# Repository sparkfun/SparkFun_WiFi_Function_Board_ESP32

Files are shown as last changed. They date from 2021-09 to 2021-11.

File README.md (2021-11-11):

SparkFun WiFi Function Board - ESP32
========================================

SparkFun WiFi Function Board - ESP32 (https://www.sparkfun.com/products/18430)

[*SparkFun WiFi Function Board - ESP32 (WRL-18430)*](https://www.sparkfun.com/products/18430)

The SparkFun MicroMod ESP32 Function Board adds additional wireless options to MicroMod Processor Boards that do not have that capability. This special function board acts as a coprocessor that takes advantage of Espressif's ESP32 WROOM to add WiFi and Bluetooth&reg; to your applications. 

At the core of the ESP32 WROOM module is the ESP32-D0WD-V3 chip which is designed to be both scalable and adaptive. ESP32 WROOM module on this board  features 16MB of flash memory, 520kB of internal SRAM, an integrated 802.11 b/g/n WiFi transceiver, and dual-mode Bluetooth capabilities. Utilizing our handy M.2 MicroMod connector, no soldering is required to connect it to your system. Simply match up the key on your processor and function board's beveled edge connector to their respective key on the M.2 connector, then secure them to the main board with screws. The ESP32 WROOM module can then be controlled using AT commands via the serial UART port.

The ESP32 Function Board comes pre-flashed with AT-command firmware and acts as a serial-to-WiFi gateway. Next to the module is a USB-C connector and CP2102 USB-to-serial converter. Whether you want to add AT commands of your own, or flash custom firmware on the ESP32, you can use this port to reprogram the ESP32.

Repository Contents
-------------------

* **/Hardware** - Eagle design files (.brd, .sch)
* **/Production** - Production panel files (.brd)

Documentation
--------------

* **[Hookup Guide](https://learn.sparkfun.com/tutorials/1998)** - Basic hookup guide

Product Versions
----------------

* [WRL-18430](https://www.sparkfun.com/products/18430) - Initial release

Version History
---------------

* v1.0 - Initial Release

License Information
-------------------

This product is _**open source**_! 

Please review the LICENSE.md file for license information. 

If you have any questions or concerns on licensing, please contact technical support on our [SparkFun forums](https://forum.sparkfun.com/viewforum.php?f=152).

Distributed as-is; no warranty is given.

- Your friends at SparkFun.

_<COLLABORATION CREDIT>_

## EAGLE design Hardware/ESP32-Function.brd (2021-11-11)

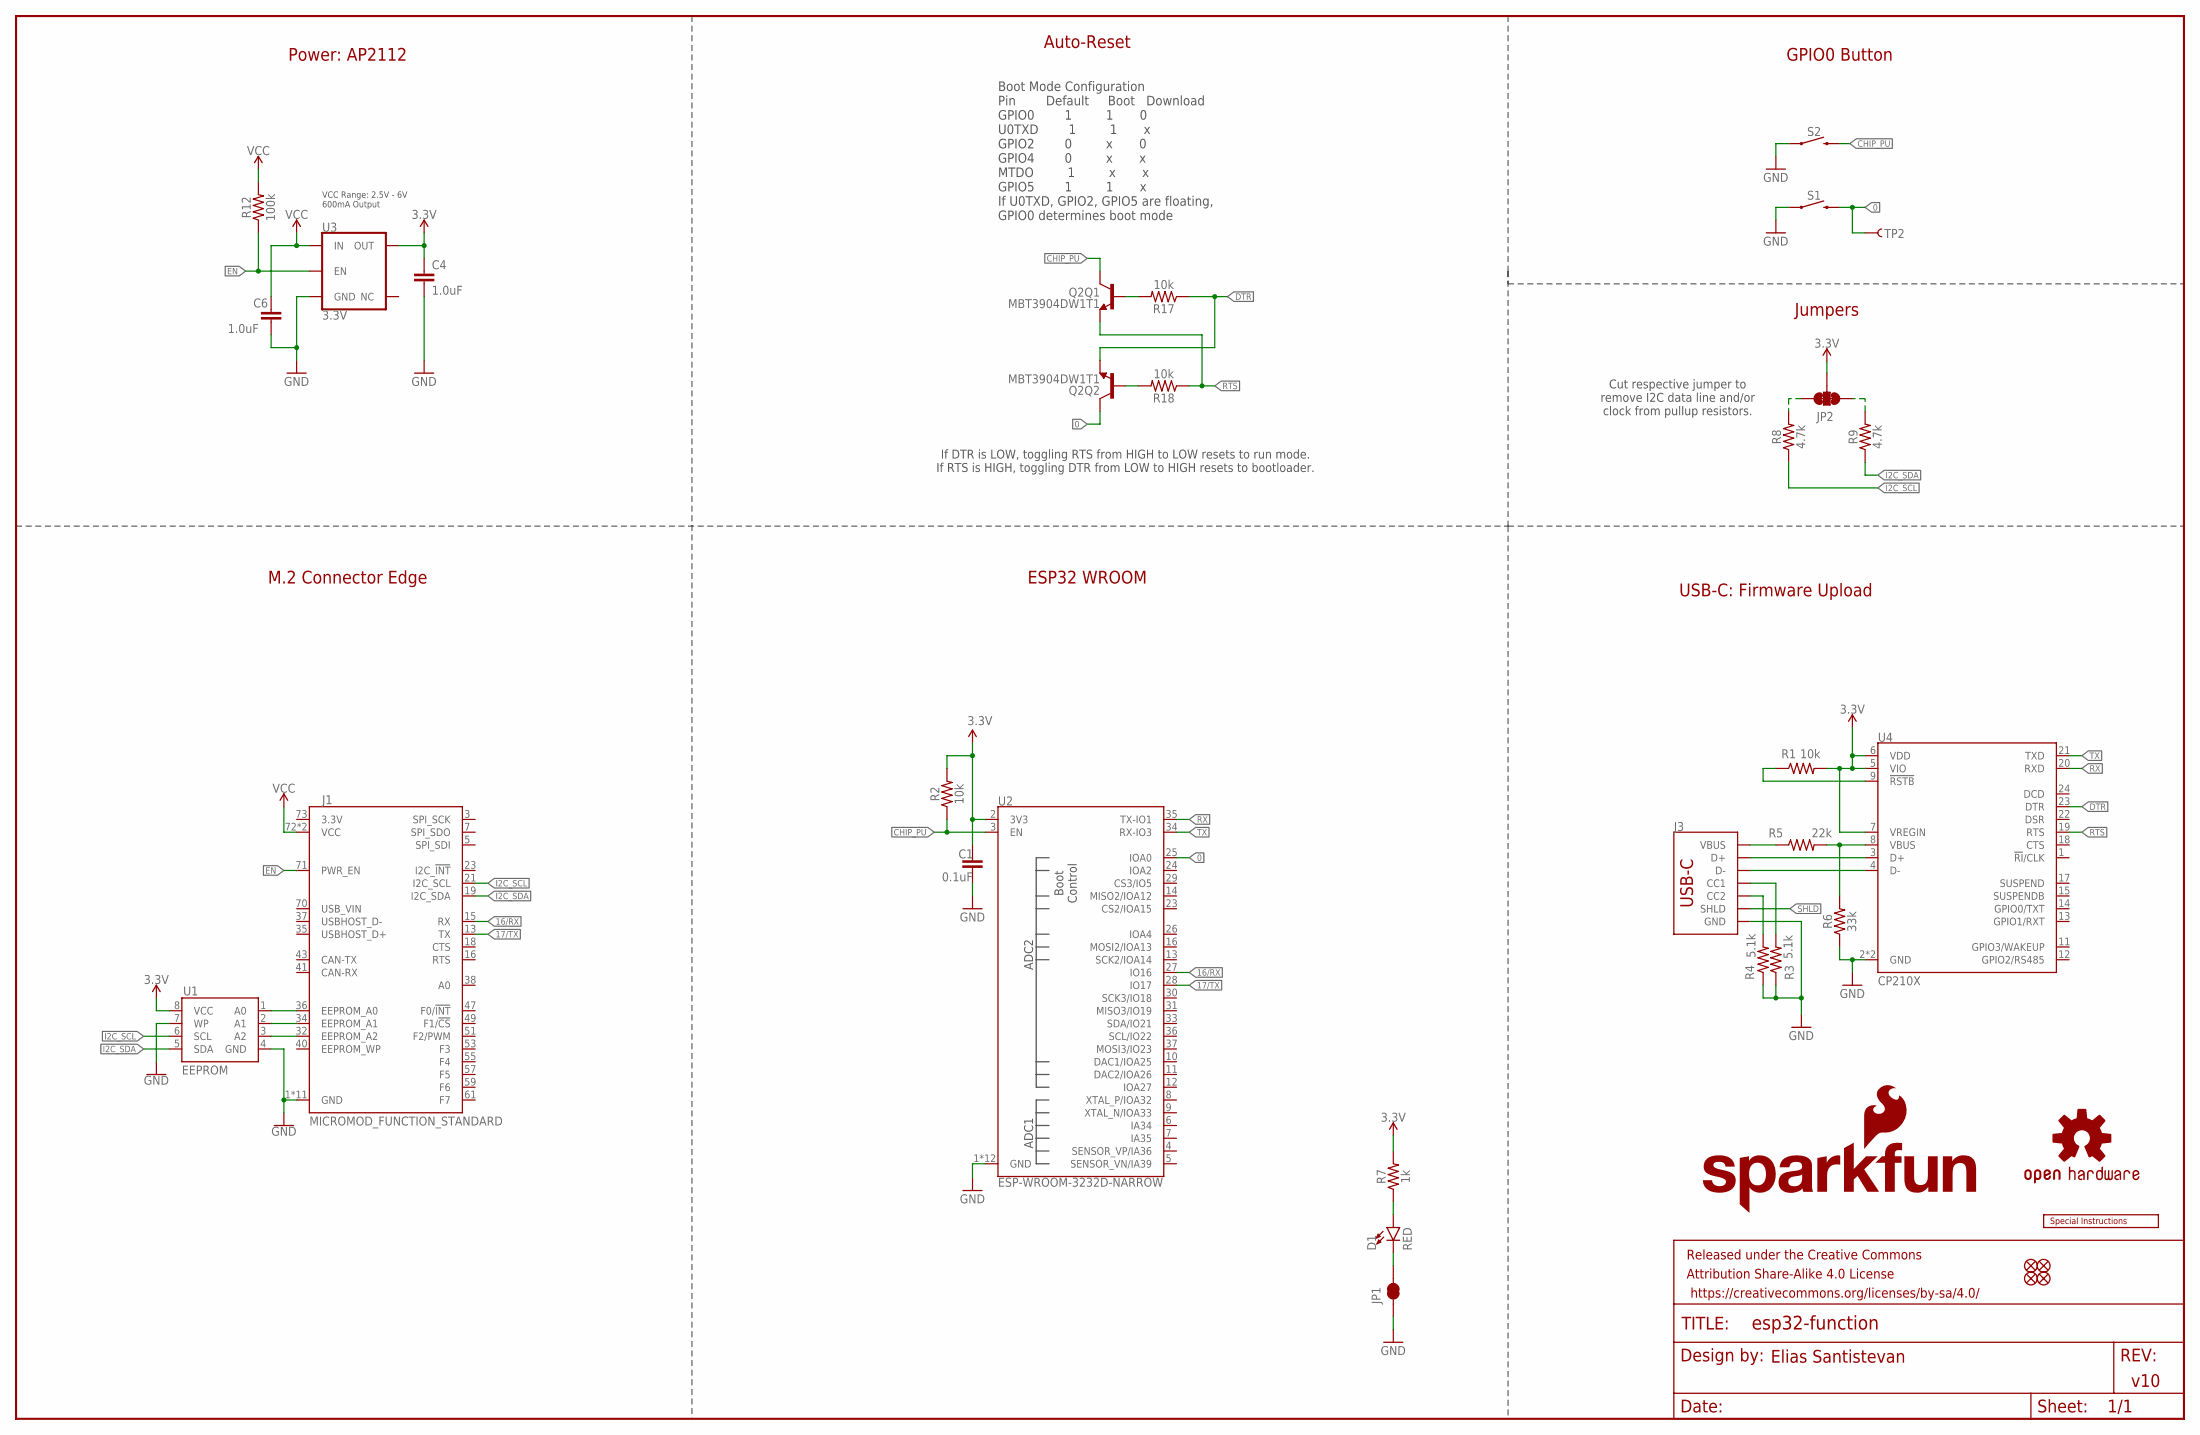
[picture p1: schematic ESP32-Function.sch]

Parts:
C1: 0.1uF; 0603
C4, C6: 1.0uF; 0603
D1: RED; LED-0603
FD1, FD2, FD3, FD4: FIDUCIAL1X2; FIDUCIAL-1X2
FRAME2: FRAME-LEDGER; CREATIVE_COMMONS
J1: MICROMOD_FUNCTION_STANDARD; M.2-CARD-E-22_FUNCTION_STANDARD
J3: USB_C_2-LAYER_PADS; USB-C-16P-2LAYER-PADS
JP1: JUMPER-SMT_2_NC_TRACE_SILK; SMT-JUMPER_2_NC_TRACE_SILK
JP2: JUMPER-SMT_3_2-NC_TRACE_SILK; SMT-JUMPER_3_2-NC_TRACE_SILK
LOGO1: SPECIAL_INSTRUCTIONS-ORDERING; ORDERING_INSTRUCTIONS
LOGO2: SFE_LOGO_NAME_FLAME.2_INCH; SFE_LOGO_NAME_FLAME_.2
LOGO3: OSHW-LOGOS; OSHW-LOGO-S
Q2: MBT3904DW1T1; SC70-6
R1, R2, R17, R18: 10k; 0603
R3, R4: 5.1k; 0603
R5: 22k; 0603
R6: 33k; 0603
R7: 1k; 0603
R8, R9: 4.7k; 0603
R12: 100k; 0603
S1, S2: MOMENTARY-SWITCH-SPST-SMD-5.2MM-TALL; TACTILE_SWITCH_SMD_5.2MM
TP2: TEST-POINTTP_15TH_THRU; TP_15TH
U1: EEPROM; SO08
U2: ESP-WROOM-3232D-NARROW; ESP-WROOM-32D-NARROW
U3: 3.3V; SOT23-5
U4: CP210X; QFN24

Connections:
0: Q2.6 (C), S1.3 (2), TP2.1, U2.25 (IOA0)
3.3V: C1.1, C4.1, JP2.2, R1.2, R2.2, R7.2, U1.8 (VCC), U2.2 (3V3), U3.5 (OUT), U4.5 (VIO), U4.6 (VDD), U4.7 (VREGIN)
16/RX: J1.15 (RX), U2.27 (IO16)
17/TX: J1.13 (TX), U2.28 (IO17)
CHIP_PU: Q2.3 (C), R2.1, S2.3 (2), U2.3 (EN)
D+: J3.A6 (D+), J3.B6 (D+), U4.3 (D+)
D-: J3.A7 (D-), J3.B7 (D-), U4.4 (D-)
DTR: Q2.1 (E), R17.1, U4.23 (DTR)
EN: J1.71 (PWR_EN), R12.1, U3.3 (EN)
GND: C1.2, C4.2, C6.2, J1.1 (GND), J1.33 (GND), J1.39 (GND), J1.45 (GND), J1.75 (GND), J1.GND1 (GND), J1.GND2 (GND), J1.GND3 (GND), J1.GND4 (GND), J1.GND5 (GND), J1.GND6 (GND), J3.GND, J3.GND2 (GND), JP1.1, R3.1, R4.1, R6.1, S1.1, S2.1, U1.4 (GND), U1.7 (WP), U2.1 (GND), U2.15 (GND), U2.38 (GND), U2.GND1 (GND), U2.GNDT1 (GND), U2.GNDT2 (GND), U2.GNDT3 (GND), U2.GNDT4 (GND), U2.GNDT5 (GND), U2.GNDT6 (GND), U2.GNDT7 (GND), U2.GNDT8 (GND), U3.2 (GND), U4.2 (GND), U4.PAD (GND)
I2C_SCL: J1.21 (I2C_SCL), R8.1, U1.6 (SCL)
I2C_SDA: J1.19 (I2C_SDA), R9.1, U1.5 (SDA)
unnamed: R1.1, U4.9 (!RSTB)
unnamed: J3.A5 (CC1), R3.2
unnamed: J3.VBUS1 (VBUS), J3.VBUS2 (VBUS), R5.1
unnamed: R5.2, R6.2, U4.8 (VBUS)
unnamed: J3.B5 (CC2), R4.2
unnamed: D1.C, JP1.2
unnamed: D1.A, R7.1
unnamed: J1.32 (EEPROM_A2), U1.3 (A2)
unnamed: J1.34 (EEPROM_A1), U1.2 (A1)
unnamed: Q2.5 (B), R17.2
unnamed: J1.36 (EEPROM_A0), U1.1 (A0)
unnamed: Q2.2 (B), R18.2
unnamed: JP2.1, R9.2
unnamed: JP2.3, R8.2
RTS: Q2.4 (E), R18.1, U4.19 (RTS)
RX: U2.35 (TX-IO1), U4.20 (RXD)
SHLD: J3.SHLD1 (SHLD), J3.SHLD2 (SHLD), J3.SHLD3 (SHLD), J3.SHLD4 (SHLD)
TX: U2.34 (RX-IO3), U4.21 (TXD)
VCC: C6.1, J1.72 (VCC), J1.74 (VCC), R12.2, U3.1 (IN)

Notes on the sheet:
Elias Santistevan
v10
Boot Mode Configuration Pin Default Boot Download GPIO0 1 1 0 U0TXD 1 1 x GPIO2 0 x 0 GPIO4 0 x x MTDO 1 x x GPIO5 1 1 x If U0TXD, GPIO2, GPIO5 are floating, GPIO0 determines boot mode
Auto-Reset
If DTR is LOW, toggling RTS from HIGH to LOW resets to run mode. If RTS is HIGH, toggling DTR from LOW to HIGH resets to bootloader.
VCC Range: 2.5V - 6V 600mA Output
Power: AP2112
ESP32 WROOM
M.2 Connector Edge
GPIO0 Button
USB-C: Firmware Upload
Jumpers
Cut respective jumper to remove I2C data line and/or clock from pullup resistors.

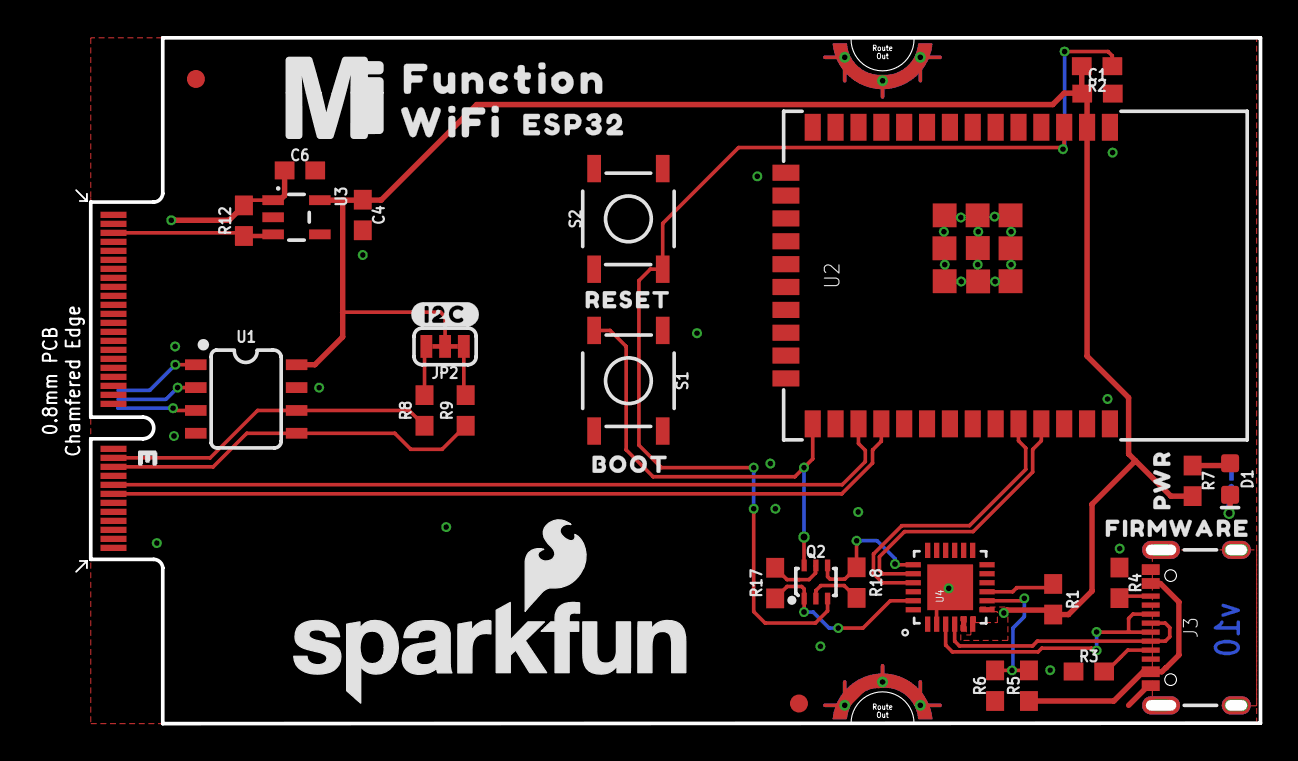
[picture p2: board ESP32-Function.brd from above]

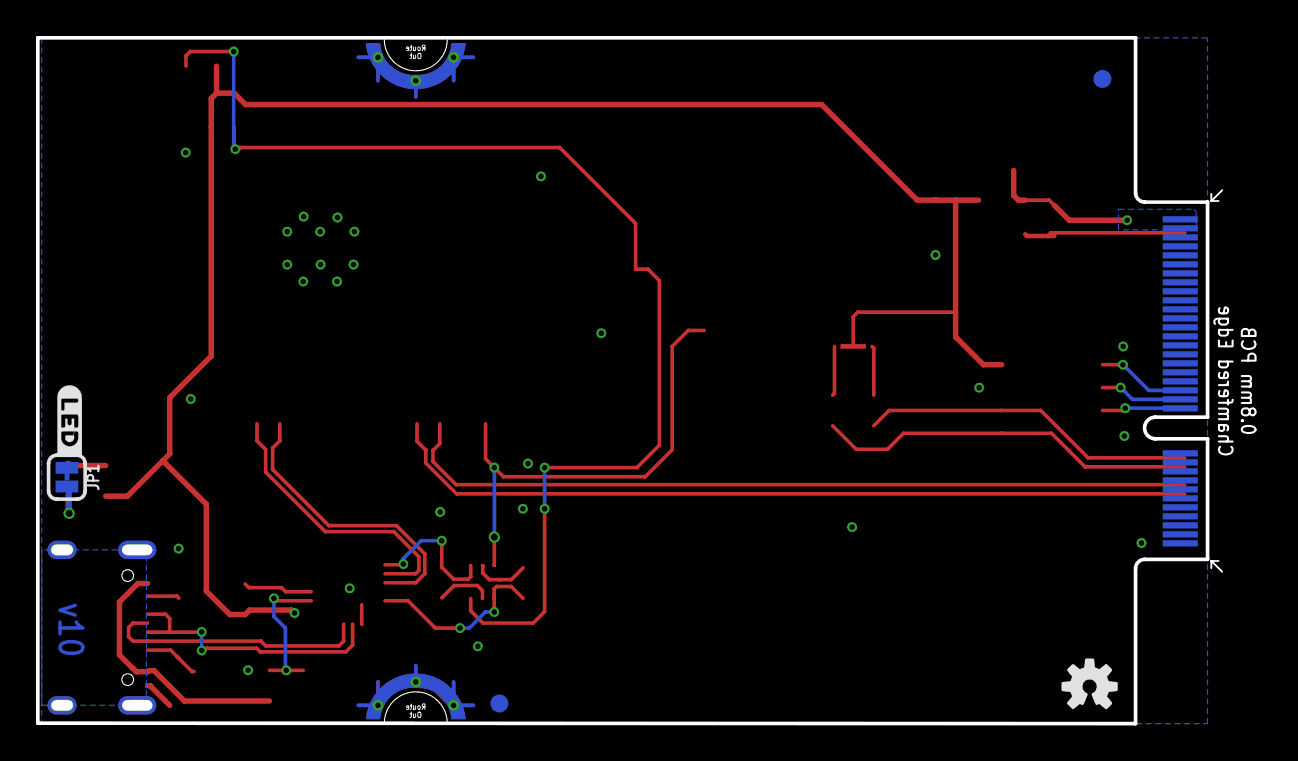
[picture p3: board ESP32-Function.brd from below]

Board: 2 copper layers, 65.8 x 38.1 mm, 46 parts (5 on the bottom side), 31 nets.

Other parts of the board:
U$1: BOOT3221
U$2: FUNCTION521
U$3: #I2C#1321540313558
U$4: ESP3212
U$5: RESET3220
U$6: MICROMOD_MI_LOGO_1
U$7: FIRMWARE3223
U$8: #LED#8
U$9: PWR3215
U$10: WIFI525

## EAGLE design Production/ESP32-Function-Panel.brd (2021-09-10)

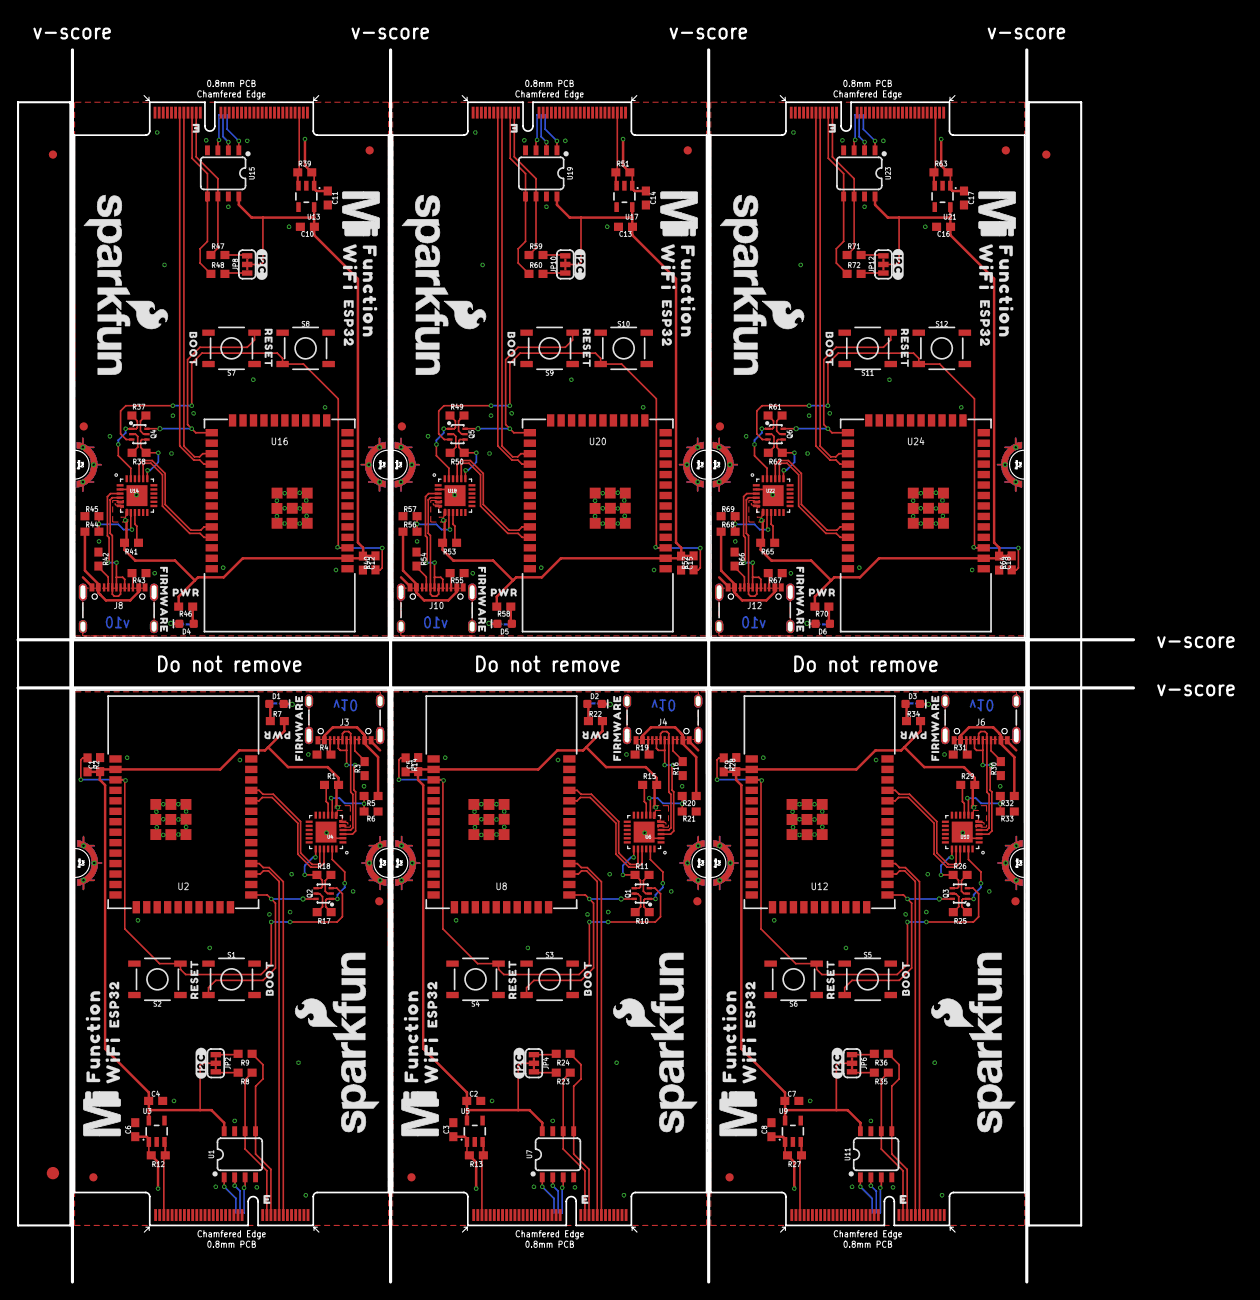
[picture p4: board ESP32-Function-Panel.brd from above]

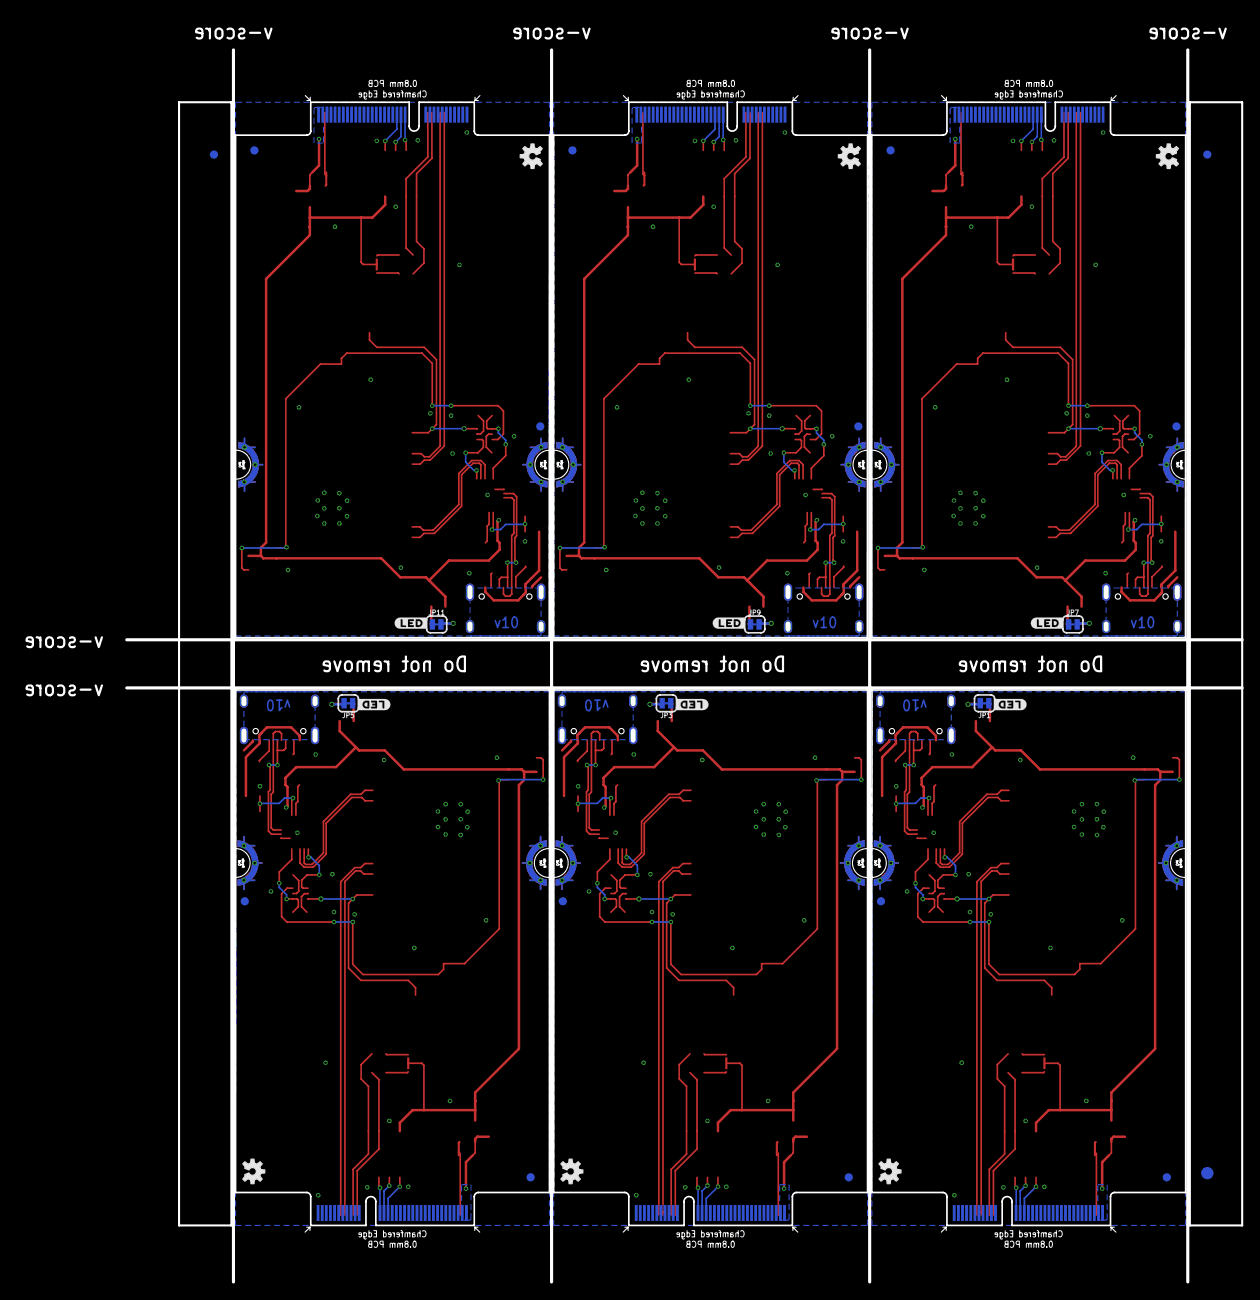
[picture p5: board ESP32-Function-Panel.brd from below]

Board: 2 copper layers, 135.4 x 149.5 mm, 270 parts (33 on the bottom side), 186 nets.

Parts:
C1, C5, C9, C12, C15, C18: 0.1uF; 0603
C2, C3, C4, C6, C7, C8, C10, C11, C13, C14, C16, C17: 1.0uF; 0603
D1, D2, D3, D4, D5, D6: RED; LED-0603
E$1, E$2, E$3, E$4: FIDUCIAL-1X2
E$5, E$6: FIDUCIAL-1.5X3
FD1, FD2, FD3, FD4, FD5, FD6, FD7, FD8, FD9, FD10, FD11, FD12, FD13, FD14, FD15, FD16, FD17, FD18, FD19, FD20, FD21, FD22, FD23, FD24: FIDUCIAL1X2; FIDUCIAL-1X2
J1, J2, J5, J7, J9, J11: MICROMOD_STANDARD; M.2-CARD-E-22_FUNCTION_STANDARD
J3, J4, J6, J8, J10, J12: USB-C-16P-2LAYER-PADS
JP1, JP3, JP5, JP7, JP9, JP11: JUMPER-SMT_2_NC_TRACE_SILK; SMT-JUMPER_2_NC_TRACE_SILK
JP2, JP4, JP6, JP8, JP10, JP12: JUMPER-SMT_3_2-NC_TRACE_SILK; SMT-JUMPER_3_2-NC_TRACE_SILK
LOGO1, LOGO2, LOGO5, LOGO7, LOGO9, LOGO11: SFE_LOGO_NAME_FLAME.2_INCH; SFE_LOGO_NAME_FLAME_.2
LOGO3, LOGO4, LOGO6, LOGO8, LOGO10, LOGO12: OSHW-LOGOS; OSHW-LOGO-S
Q1, Q2, Q3, Q4, Q5, Q6: MBT3904DW1T1; SC70-6
R1, R2, R10, R11, R14, R15, R17, R18, R25, R26, R28, R29, R37, R38, R40, R41, R49, R50, R52, R53, R61, R62, R64, R65: 10k; 0603
R3, R4, R16, R19, R30, R31, R42, R43, R54, R55, R66, R67: 5.1k; 0603
R5, R20, R32, R44, R56, R68: 22k; 0603
R6, R21, R33, R45, R57, R69: 33k; 0603
R7, R22, R34, R46, R58, R70: 1k; 0603
R8, R9, R23, R24, R35, R36, R47, R48, R59, R60, R71, R72: 4.7k; 0603
R12, R13, R27, R39, R51, R63: 100k; 0603
S1, S2, S3, S4, S5, S6, S7, S8, S9, S10, S11, S12: MOMENTARY-SWITCH-SPST-SMD-5.2MM-TALL; TACTILE_SWITCH_SMD_5.2MM
TP1, TP2, TP3, TP4, TP5, TP6: TEST-POINTTP_15TH_THRU; TP_15TH
U1, U7, U11, U15, U19, U23: EEPROM; SO08
U2, U8, U12, U16, U20, U24: ESP-WROOM-3232D-NARROW; ESP-WROOM-32D-NARROW
U3, U5, U9, U13, U17, U21: 3.3V; SOT23-5
U4, U6, U10, U14, U18, U22: CP210X; QFN24
U$1, U$11, U$21, U$31, U$41, U$51: BOOT3221
U$2, U$17, U$27, U$37, U$47, U$57: FUNCTION521
U$3, U$20, U$30, U$40, U$50, U$60: #I2C#1321540313558
U$4, U$12, U$22, U$32, U$42, U$52: ESP3212
U$5, U$14, U$24, U$34, U$44, U$54: RESET3220
U$6, U$18, U$28, U$38, U$48, U$58: MICROMOD_MI_LOGO_1
U$7, U$13, U$23, U$33, U$43, U$53: FIRMWARE3223
U$8, U$15, U$25, U$35, U$45, U$55: #LED#8
U$9, U$16, U$26, U$36, U$46, U$56: PWR3215
U$10, U$19, U$29, U$39, U$49, U$59: WIFI525

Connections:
0: Q2.6, S1.3, TP2.1, U2.25
1: Q1.6, S3.3, TP1.1, U8.25
2: Q3.6, S5.3, TP3.1, U12.25
3: Q4.6, S7.3, TP4.1, U16.25
3.3V: C1.1, C4.1, JP2.2, R1.2, R2.2, R7.2, U1.8, U2.2, U3.5, U4.5, U4.6, U4.7
3.3V1: C2.1, C5.1, JP4.2, R14.2, R15.2, R22.2, U5.5, U6.5, U6.6, U6.7, U7.8, U8.2
3.3V2: C7.1, C9.1, JP6.2, R28.2, R29.2, R34.2, U9.5, U10.5, U10.6, U10.7, U11.8, U12.2
3.3V3: C10.1, C12.1, JP8.2, R40.2, R41.2, R46.2, U13.5, U14.5, U14.6, U14.7, U15.8, U16.2
3.3V4: C13.1, C15.1, JP10.2, R52.2, R53.2, R58.2, U17.5, U18.5, U18.6, U18.7, U19.8, U20.2
3.3V5: C16.1, C18.1, JP12.2, R64.2, R65.2, R70.2, U21.5, U22.5, U22.6, U22.7, U23.8, U24.2
4: Q5.6, S9.3, TP5.1, U20.25
5: Q6.6, S11.3, TP6.1, U24.25
16/RX: J1.15, U2.27
16/RX1: J2.15, U8.27
16/RX2: J5.15, U12.27
16/RX3: J7.15, U16.27
16/RX4: J9.15, U20.27
16/RX5: J11.15, U24.27
17/TX: J1.13, U2.28
17/TX1: J2.13, U8.28
17/TX2: J5.13, U12.28
17/TX3: J7.13, U16.28
17/TX4: J9.13, U20.28
17/TX5: J11.13, U24.28
CHIP_PU: Q2.3, R2.1, S2.3, U2.3
CHIP_PU1: Q1.3, R14.1, S4.3, U8.3
CHIP_PU2: Q3.3, R28.1, S6.3, U12.3
CHIP_PU3: Q4.3, R40.1, S8.3, U16.3
CHIP_PU4: Q5.3, R52.1, S10.3, U20.3
CHIP_PU5: Q6.3, R64.1, S12.3, U24.3
D+: J3.A6, J3.B6, U4.3
D+1: J4.A6, J4.B6, U6.3
D+2: J6.A6, J6.B6, U10.3
D+3: J8.A6, J8.B6, U14.3
D+4: J10.A6, J10.B6, U18.3
D+5: J12.A6, J12.B6, U22.3
D-: J3.A7, J3.B7, U4.4
D-1: J4.A7, J4.B7, U6.4
D-2: J6.A7, J6.B7, U10.4
D-3: J8.A7, J8.B7, U14.4
D-4: J10.A7, J10.B7, U18.4
D-5: J12.A7, J12.B7, U22.4
DTR: Q2.1, R17.1, U4.23
DTR1: Q1.1, R10.1, U6.23
DTR2: Q3.1, R25.1, U10.23
DTR3: Q4.1, R37.1, U14.23
DTR4: Q5.1, R49.1, U18.23
DTR5: Q6.1, R61.1, U22.23
EN: J1.71, R12.1, U3.3
EN1: J2.71, R13.1, U5.3
EN2: J5.71, R27.1, U9.3
EN3: J7.71, R39.1, U13.3
EN4: J9.71, R51.1, U17.3
EN5: J11.71, R63.1, U21.3
GND: C1.2, C4.2, C6.2, J1.1, J1.33, J1.39, J1.45, J1.75, J1.GND1, J1.GND2, J1.GND3, J1.GND4, J1.GND5, J1.GND6, J3.GND, J3.GND2, JP1.1, R3.1, R4.1, R6.1, S1.1, S2.1, U1.4, U1.7, U2.1, U2.15, U2.38, U2.GND1, U2.GNDT1, U2.GNDT2, U2.GNDT3, U2.GNDT4, U2.GNDT5, U2.GNDT6, U2.GNDT7, U2.GNDT8, U3.2, U4.2, U4.PAD
GND1: C2.2, C3.2, C5.2, J2.1, J2.33, J2.39, J2.45, J2.75, J2.GND1, J2.GND2, J2.GND3, J2.GND4, J2.GND5, J2.GND6, J4.GND, J4.GND2, JP3.1, R16.1, R19.1, R21.1, S3.1, S4.1, U5.2, U6.2, U6.PAD, U7.4, U7.7, U8.1, U8.15, U8.38, U8.GND1, U8.GNDT1, U8.GNDT2, U8.GNDT3, U8.GNDT4, U8.GNDT5, U8.GNDT6, U8.GNDT7, U8.GNDT8
GND2: C7.2, C8.2, C9.2, J5.1, J5.33, J5.39, J5.45, J5.75, J5.GND1, J5.GND2, J5.GND3, J5.GND4, J5.GND5, J5.GND6, J6.GND, J6.GND2, JP5.1, R30.1, R31.1, R33.1, S5.1, S6.1, U9.2, U10.2, U10.PAD, U11.4, U11.7, U12.1, U12.15, U12.38, U12.GND1, U12.GNDT1, U12.GNDT2, U12.GNDT3, U12.GNDT4, U12.GNDT5, U12.GNDT6, U12.GNDT7, U12.GNDT8
GND3: C10.2, C11.2, C12.2, J7.1, J7.33, J7.39, J7.45, J7.75, J7.GND1, J7.GND2, J7.GND3, J7.GND4, J7.GND5, J7.GND6, J8.GND, J8.GND2, JP7.1, R42.1, R43.1, R45.1, S7.1, S8.1, U13.2, U14.2, U14.PAD, U15.4, U15.7, U16.1, U16.15, U16.38, U16.GND1, U16.GNDT1, U16.GNDT2, U16.GNDT3, U16.GNDT4, U16.GNDT5, U16.GNDT6, U16.GNDT7, U16.GNDT8
GND4: C13.2, C14.2, C15.2, J9.1, J9.33, J9.39, J9.45, J9.75, J9.GND1, J9.GND2, J9.GND3, J9.GND4, J9.GND5, J9.GND6, J10.GND, J10.GND2, JP9.1, R54.1, R55.1, R57.1, S9.1, S10.1, U17.2, U18.2, U18.PAD, U19.4, U19.7, U20.1, U20.15, U20.38, U20.GND1, U20.GNDT1, U20.GNDT2, U20.GNDT3, U20.GNDT4, U20.GNDT5, U20.GNDT6, U20.GNDT7, U20.GNDT8
GND5: C16.2, C17.2, C18.2, J11.1, J11.33, J11.39, J11.45, J11.75, J11.GND1, J11.GND2, J11.GND3, J11.GND4, J11.GND5, J11.GND6, J12.GND, J12.GND2, JP11.1, R66.1, R67.1, R69.1, S11.1, S12.1, U21.2, U22.2, U22.PAD, U23.4, U23.7, U24.1, U24.15, U24.38, U24.GND1, U24.GNDT1, U24.GNDT2, U24.GNDT3, U24.GNDT4, U24.GNDT5, U24.GNDT6, U24.GNDT7, U24.GNDT8
I2C_SCL: J1.21, R8.1, U1.6
I2C_SCL1: J2.21, R23.1, U7.6
I2C_SCL2: J5.21, R35.1, U11.6
I2C_SCL3: J7.21, R47.1, U15.6
I2C_SCL4: J9.21, R59.1, U19.6
I2C_SCL5: J11.21, R71.1, U23.6
I2C_SDA: J1.19, R9.1, U1.5
I2C_SDA1: J2.19, R24.1, U7.5
I2C_SDA2: J5.19, R36.1, U11.5
I2C_SDA3: J7.19, R48.1, U15.5
I2C_SDA4: J9.19, R60.1, U19.5
I2C_SDA5: J11.19, R72.1, U23.5
unnamed: R1.1, U4.9
unnamed: J3.A5, R3.2
unnamed: J3.VBUS1, J3.VBUS2, R5.1
unnamed: R5.2, R6.2, U4.8
unnamed: J3.B5, R4.2
unnamed: D1.C, JP1.2
unnamed: D1.A, R7.1
unnamed: J1.32, U1.3
unnamed: J1.34, U1.2
unnamed: Q2.5, R17.2
unnamed: J1.36, U1.1
unnamed: Q2.2, R18.2
unnamed: JP2.1, R9.2
unnamed: JP2.3, R8.2
unnamed: Q1.5, R10.2
unnamed: Q1.2, R11.2
unnamed: J4.A5, R16.2
unnamed: J4.B5, R19.2
unnamed: R15.1, U6.9
unnamed: J4.VBUS1, J4.VBUS2, R20.1
unnamed: R20.2, R21.2, U6.8
unnamed: D2.C, JP3.2
unnamed: D2.A, R22.1
unnamed: J2.32, U7.3
unnamed: J2.34, U7.2
unnamed: J2.36, U7.1
unnamed: JP4.1, R24.2
unnamed: JP4.3, R23.2
unnamed: Q3.5, R25.2
unnamed: Q3.2, R26.2
unnamed: J6.A5, R30.2
unnamed: J6.B5, R31.2
unnamed: R29.1, U10.9
unnamed: J6.VBUS1, J6.VBUS2, R32.1
unnamed: R32.2, R33.2, U10.8
unnamed: D3.C, JP5.2
unnamed: D3.A, R34.1
unnamed: J5.32, U11.3
unnamed: J5.34, U11.2
unnamed: J5.36, U11.1
unnamed: JP6.1, R36.2
unnamed: JP6.3, R35.2
unnamed: Q4.5, R37.2
unnamed: Q4.2, R38.2
unnamed: J8.A5, R42.2
unnamed: J8.B5, R43.2
unnamed: R41.1, U14.9
unnamed: J8.VBUS1, J8.VBUS2, R44.1
unnamed: R44.2, R45.2, U14.8
unnamed: D4.C, JP7.2
unnamed: D4.A, R46.1
unnamed: J7.32, U15.3
unnamed: J7.34, U15.2
unnamed: J7.36, U15.1
unnamed: JP8.1, R48.2
unnamed: JP8.3, R47.2
unnamed: Q5.5, R49.2
unnamed: Q5.2, R50.2
unnamed: J10.A5, R54.2
unnamed: J10.B5, R55.2
unnamed: R53.1, U18.9
unnamed: J10.VBUS1, J10.VBUS2, R56.1
unnamed: R56.2, R57.2, U18.8
unnamed: D5.C, JP9.2
unnamed: D5.A, R58.1
unnamed: J9.32, U19.3
unnamed: J9.34, U19.2
unnamed: J9.36, U19.1
unnamed: JP10.1, R60.2
unnamed: JP10.3, R59.2
unnamed: Q6.5, R61.2
unnamed: Q6.2, R62.2
unnamed: J12.A5, R66.2
unnamed: J12.B5, R67.2
unnamed: R65.1, U22.9
unnamed: J12.VBUS1, J12.VBUS2, R68.1
unnamed: R68.2, R69.2, U22.8
unnamed: D6.C, JP11.2
unnamed: D6.A, R70.1
unnamed: J11.32, U23.3
unnamed: J11.34, U23.2
unnamed: J11.36, U23.1
unnamed: JP12.1, R72.2
unnamed: JP12.3, R71.2
RTS: Q2.4, R18.1, U4.19
RTS1: Q1.4, R11.1, U6.19
RTS2: Q3.4, R26.1, U10.19
RTS3: Q4.4, R38.1, U14.19
RTS4: Q5.4, R50.1, U18.19
RTS5: Q6.4, R62.1, U22.19
RX: U2.35, U4.20
RX1: U6.20, U8.35
RX2: U10.20, U12.35
RX3: U14.20, U16.35
RX4: U18.20, U20.35
RX5: U22.20, U24.35
SHLD: J3.SHLD1, J3.SHLD2, J3.SHLD3, J3.SHLD4
SHLD1: J4.SHLD1, J4.SHLD2, J4.SHLD3, J4.SHLD4
SHLD2: J6.SHLD1, J6.SHLD2, J6.SHLD3, J6.SHLD4
SHLD3: J8.SHLD1, J8.SHLD2, J8.SHLD3, J8.SHLD4
SHLD4: J10.SHLD1, J10.SHLD2, J10.SHLD3, J10.SHLD4
SHLD5: J12.SHLD1, J12.SHLD2, J12.SHLD3, J12.SHLD4
TX: U2.34, U4.21
TX1: U6.21, U8.34
TX2: U10.21, U12.34
TX3: U14.21, U16.34
TX4: U18.21, U20.34
TX5: U22.21, U24.34
VCC: C6.1, J1.72, J1.74, R12.2, U3.1
VCC1: C3.1, J2.72, J2.74, R13.2, U5.1
VCC2: C8.1, J5.72, J5.74, R27.2, U9.1
VCC3: C11.1, J7.72, J7.74, R39.2, U13.1
VCC4: C14.1, J9.72, J9.74, R51.2, U17.1
VCC5: C17.1, J11.72, J11.74, R63.2, U21.1

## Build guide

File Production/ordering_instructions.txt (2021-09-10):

panel size, 130x137mm
PCB thickness, 0.8mm
number of layers, 2
soldermask color, Red
silkscreen color, White
oz copper, 1oz
finish, ENIG
stencils, top
pcs per panel, 6
min trace width, 0.2032mm / 0.0080in
min drill size, 0.3048mm / 0.0120in

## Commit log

2021-08-17 Initial commit (post-prototype, pre-finalized-for-REDs)
    [ESP32-Function.GBL, ESP32-Function.GBO, ESP32-Function.GBP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]
2021-09-01 Moves to 0603 components where able, adds silk, fixes traces affected by move to 0603
    * removes wire stubs
    * Fixes random air wires
    [ESP32-Function.brd, ESP32-Function.sch]
2021-09-10 Adds I2C pullups and jumper to remove them, rearranges silk
    [ESP32-Function.brd, ESP32-Function.sch]
2021-09-10 Panel v10
    [ESP32-Function-Panel.GBL, ESP32-Function-Panel.GBO, ESP32-Function-Panel.GBP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]
2021-09-13 Moves production files to correct location
    [ESP32-Function-Panel.GBL, ESP32-Function-Panel.GBO, ESP32-Function-Panel.GBP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]
2021-11-03 Updates function board symbol
    [ESP32-Function.brd, ESP32-Function.sch]
2021-11-11 Updates the design to use the Micromod-function device in the official SFE Eagle Libs
    [ESP32-Function.brd, ESP32-Function.sch]

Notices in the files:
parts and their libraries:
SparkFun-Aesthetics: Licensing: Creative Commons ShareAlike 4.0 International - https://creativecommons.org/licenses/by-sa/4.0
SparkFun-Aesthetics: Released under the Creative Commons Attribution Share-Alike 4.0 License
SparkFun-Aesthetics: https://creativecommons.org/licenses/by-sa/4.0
